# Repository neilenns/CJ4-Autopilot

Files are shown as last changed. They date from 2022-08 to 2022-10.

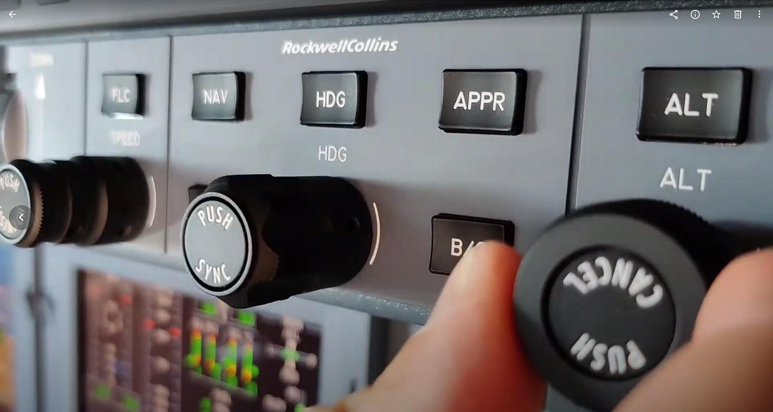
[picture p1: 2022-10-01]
Real world knobs.png

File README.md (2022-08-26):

# KiBot CI/CD template repository for KiCad 6

This repository provides a ready-to-go CI/CD workflow for KiCad 6 with GitHub actions. Using KiCad5? [See my other repo](https://github.com/neilenns/KiBot-CICD-Template).

## Features of this repository template

1. Integration with GitHub releases to automatically produce documentation and
   fabrication files on every GitHub release, including automatic date and version
   stamping of schematics and PCBs.
2. KiBot preflighting on every pull request (ERC/DRC checks disabled by default).
3. VSCode dev container and default build task for easy local testing of KiBot scripts.

## Creating your GitHub repo and KiCad project

To create a KiCad project using this GitHub template:

1. Hit the _Use this template_ button then follow the steps from GitHub to create a copy of the repo. **The repository name must exactly match the name of the KiCad project.
   Do not use spaces in either the repository or the project name.**
2. Clone the new repo locally.
3. Go to _File_ > _New_ > _Project..._ in KiCad.
4. Name the project the exact same name as the GitHub repository name.
5. Uncheck the _Create a new directory for this project_ option. **This is very important!**
6. Save the project into the top level of the folder for the GitHub repository.

Do not use spaces in the GitHub repository or KiCad project name. Use underscores or hyphens instead, for example `TBM930_De-Ice_-_Panel` or `Collins-FMS-3000`.

If you've done all the steps correctly the folder structure will look similar like this:



Notice that the folder name (which is also the GitHub repo name) and project name are exactly the same and there are no spaces.

## Setting up date and version number replacement

The GitHub automation can automatically set the date and version number in the generated schematic and PCBs. Before using this make sure
to set the timezone to your local timezone in the `.github\workflows\documentation-only.yml` and `.github\workflows\release.yml` files.

Version number and date replacement is done on the `%%version%%` and `%%date%%` string wherever they appear in your `.sch` and `.kicad_pcb` files.
Typically you will use them in the _Page settings_ dialog for the schematic and as text in silkscreen and/or copper layers on your board:





## Documentation generated

The following documents are generated on every release build:

- Interactive BOM - HTML
- Schematic - PDF
- PCB front copper and explanatory drawings layers - PDF
- PCB back copper and explanatory drawings layers - PDF
- 3D render - STEP
- PCB front - JPEG
- PCB back - JPEG

These documents can also be generated by manually running the `KiBot - Generate documentation` action on GitHub.

## Fabrication files generated

The following fabrication files are generated on every release build:

- JLCPCB gerbers and drill files, with BOM and placement files for SMT service
- PCBWay gerbers and drill files

The fabrication files can also be generated by manually running the `KiBot - Release` action on GitHub.

## How this works

A complete CodeTour is included in this repository that walks through all the components
of how KiBot scripts and GitHub actions work. [Use github.dev to view the CodeTour](https://github.dev/neilenns/KiBot-CICD-Template)!

## Running builds locally

This repository template includes the files necessary to run in a VSCode dev container,
which dramatically reduces the effort required to use KiBot on Windows machines.

Never used VSCode remote containers before on Windows? Here's how to get set up:

1. From a PowerShell install WSL2 with this command: `wsl --install`
2. Install [Visual Studio Code](https://code.visualstudio.com/Download) and Docker Desktop(https://www.docker.com/products/docker-desktop)
3. Install the [Remote Containers](https://marketplace.visualstudio.com/items?itemName=ms-vscode-remote.remote-containers) extension for VSCode

When installing Docker Desktop you may be told you have to enable virtualization in your computer's BIOS. Setting that up
is outside the scope of this readme but isn't hard. Just do a web search for your motherboard for how to enter the BIOS
and what the exact name of the setting is, then turn it on.

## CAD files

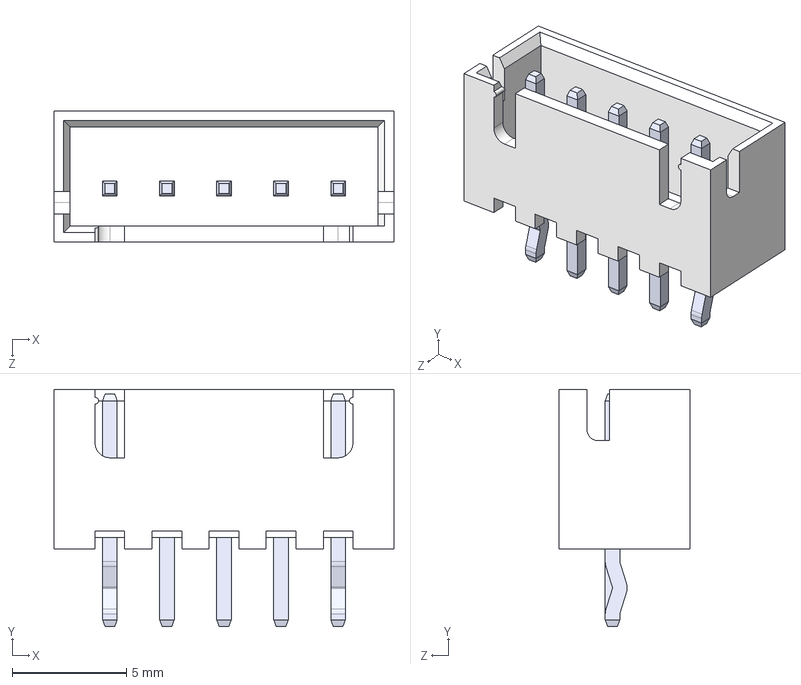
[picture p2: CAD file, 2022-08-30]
3D Models/B5B-XH-A-LF--SN---3DModel-STEP-418109.STEP
14.9 x 10.4 x 5.75 mm

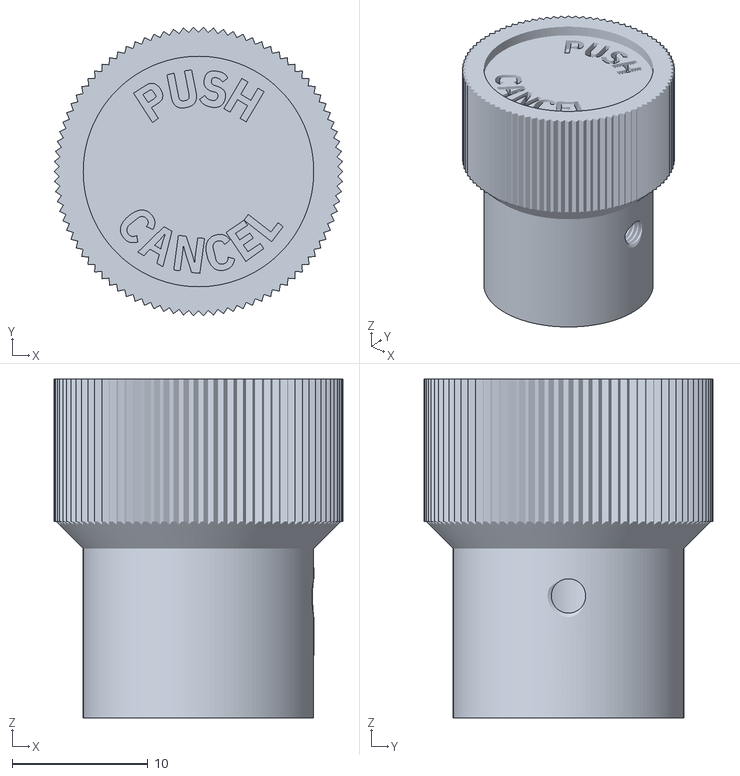
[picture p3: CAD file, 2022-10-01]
3D prints/ALT knob.stl
21.3 x 21.3 x 25.0

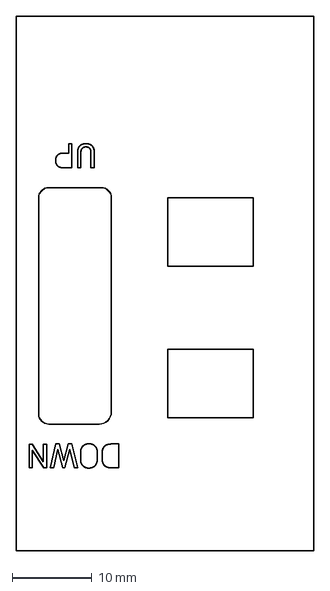
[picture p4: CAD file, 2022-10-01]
down up.dxf
37.3 x 67.2 mm

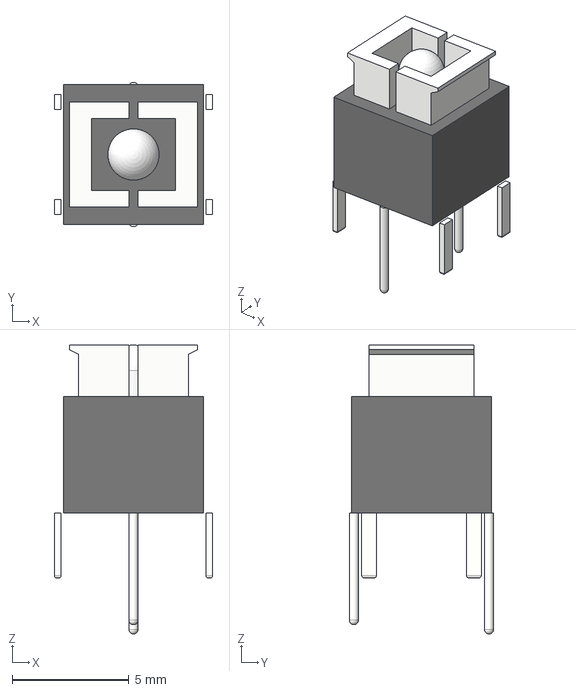
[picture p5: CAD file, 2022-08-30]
3D Models/6x6 LED button.step
6.78 x 6.20 x 12.4 mm

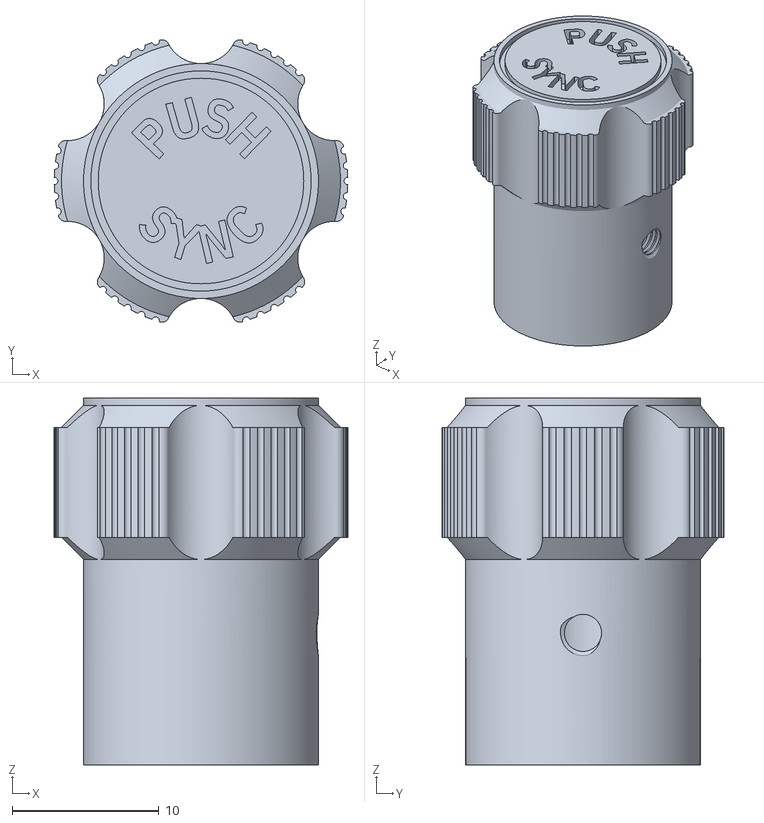
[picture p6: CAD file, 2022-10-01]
3D prints/HDG knob.stl
20.0 x 19.2 x 25.0

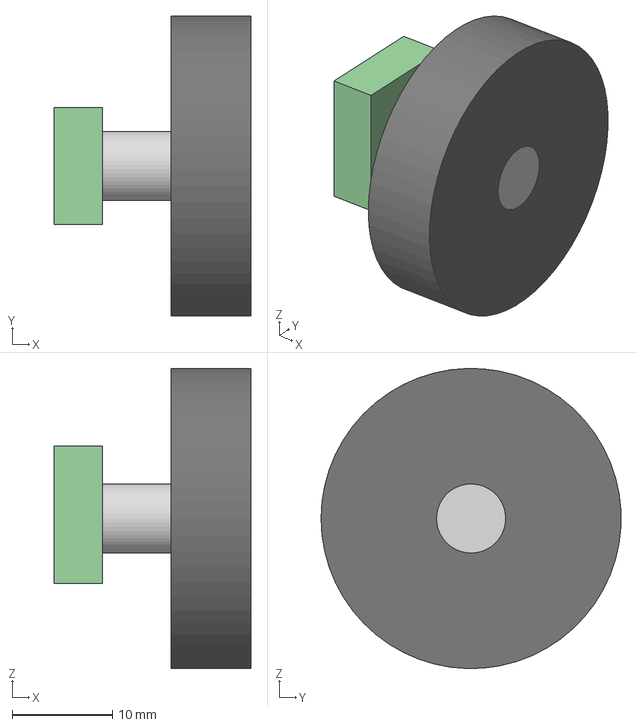
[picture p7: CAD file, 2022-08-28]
3D Models/Right angle encoder.step
19.6 x 30.0 x 30.0 mm

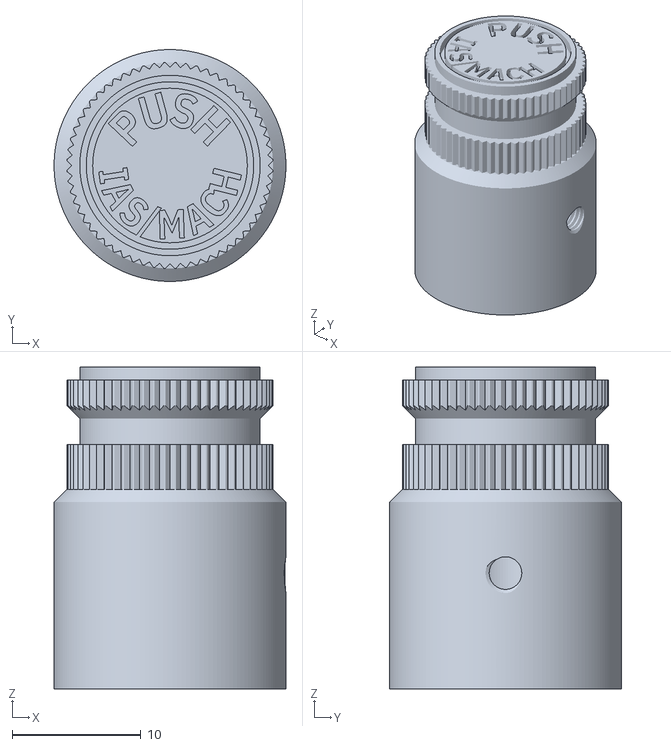
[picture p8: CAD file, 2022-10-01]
3D prints/SPEED knob.stl
18.0 x 18.0 x 25.0

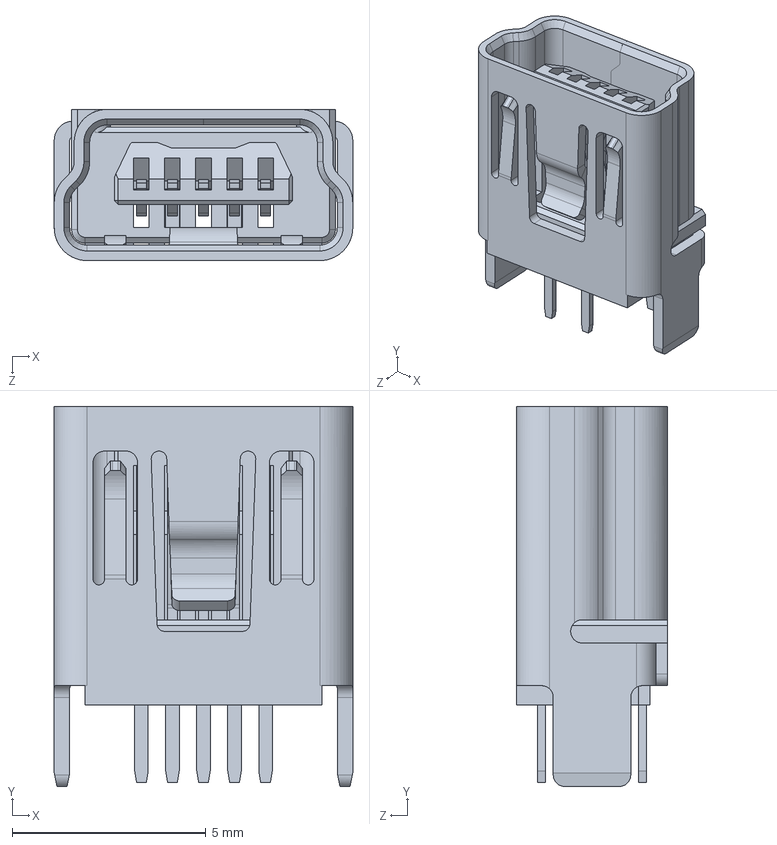
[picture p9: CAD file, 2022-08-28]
3D Models/UE25BE5510H--3DModel-STEP-533217.STEP
7.70 x 9.80 x 3.90 mm

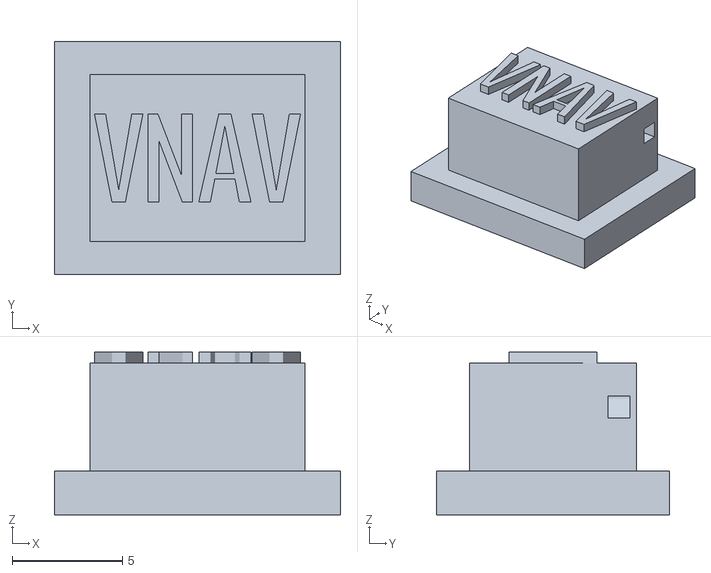
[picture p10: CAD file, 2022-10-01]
3D prints/VNAV cap.stl
13.0 x 10.6 x 7.40

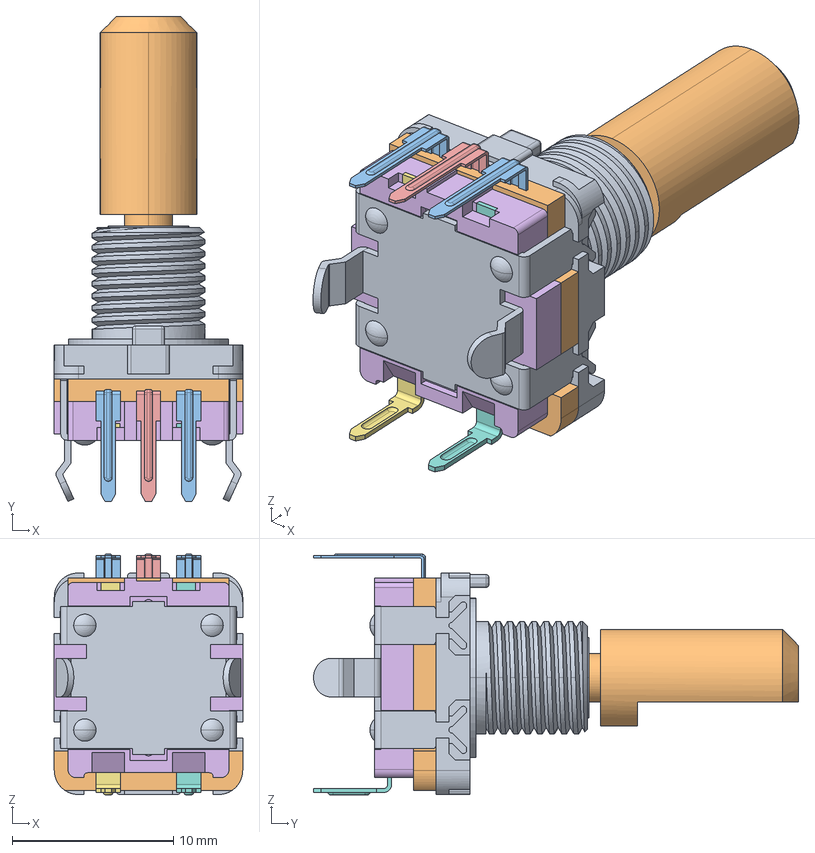
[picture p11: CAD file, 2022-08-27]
3D Models/EN11-HSM1BF20--3DModel-STEP-412949.STEP
11.7 x 30.1 x 14.9 mm

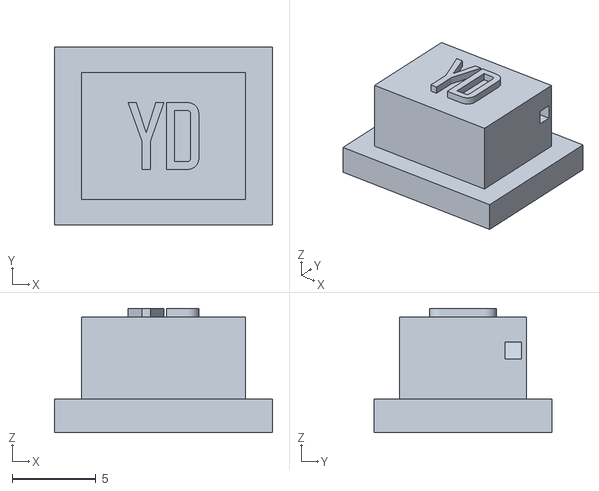
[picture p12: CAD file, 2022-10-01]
3D prints/YD cap.stl
13.0 x 10.6 x 7.40

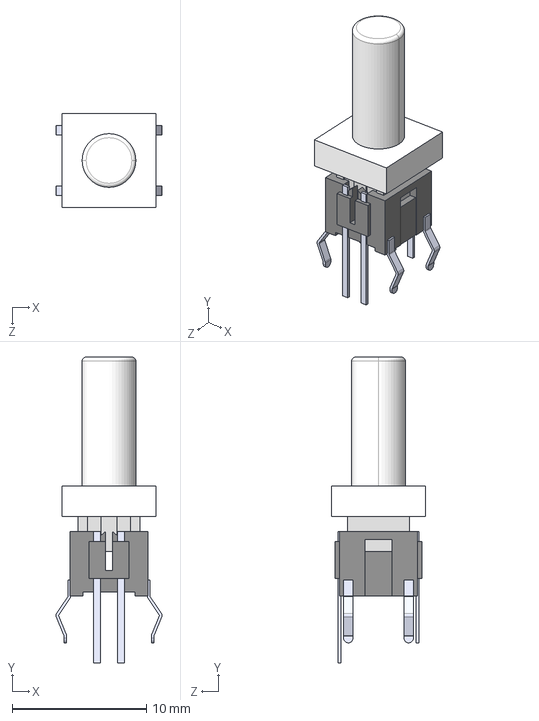
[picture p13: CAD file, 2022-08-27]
3D Models/TC002-N11AS1XT-RGB--3DModel-STEP-418109.STEP
7.90 x 22.8 x 7.00 mm

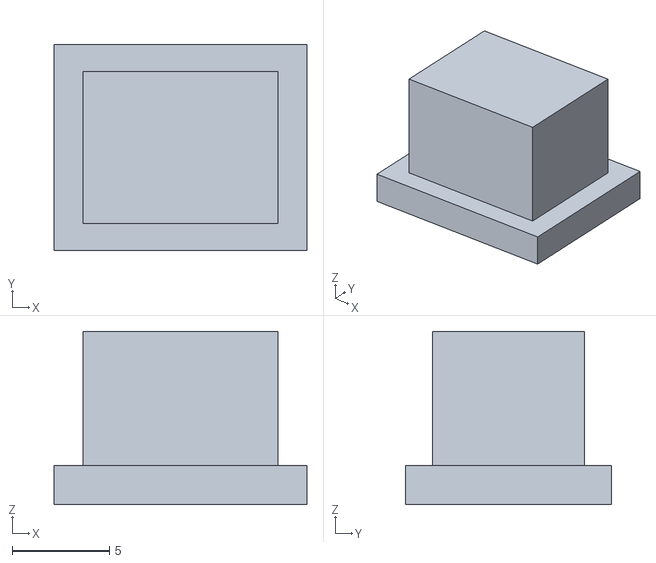
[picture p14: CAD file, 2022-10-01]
3D prints/Blank cap.stl
13.0 x 10.6 x 8.90

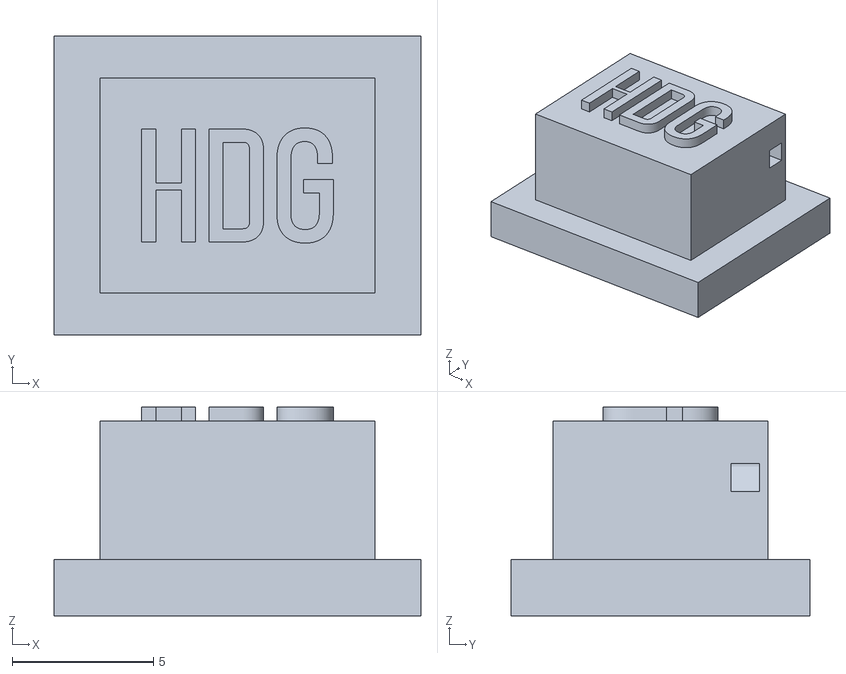
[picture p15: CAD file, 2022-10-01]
3D prints/HDG cap.stl
13.0 x 10.6 x 7.40

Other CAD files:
3D prints/VS cap.stl
3D prints/CRS knob.stl
3D prints/HALF BANK cap.stl
3D prints/AP XFR cap.stl
3D prints/ALT cap.stl
3D prints/APPR cap.stl
3D prints/BC cap.stl
3D prints/Cap.stl
3D prints/FD cap.stl
3D prints/FLC cap.stl
3D prints/Mounting bracket - left.stl
3D prints/Mounting bracket - right.stl
3D prints/NAV cap.stl

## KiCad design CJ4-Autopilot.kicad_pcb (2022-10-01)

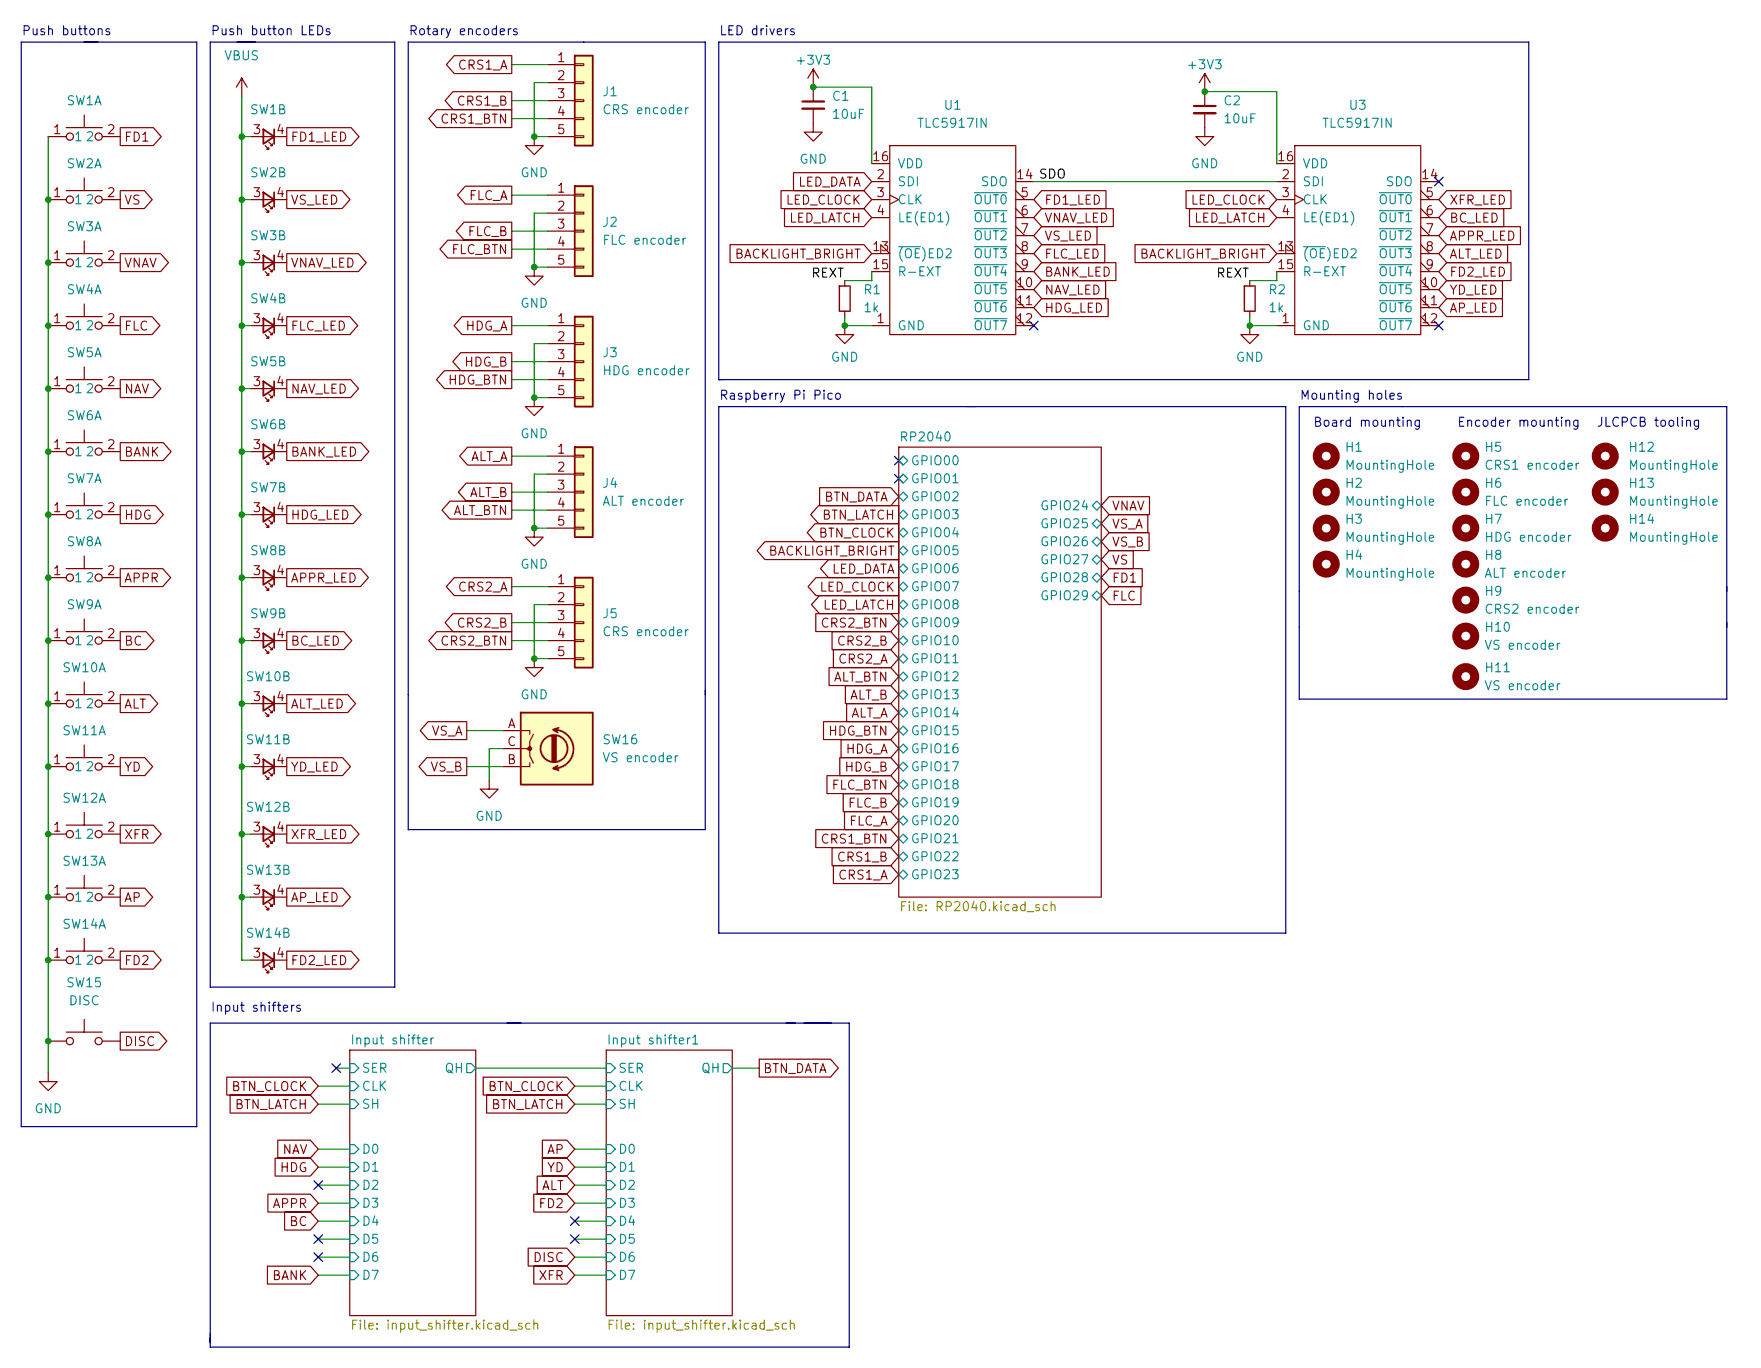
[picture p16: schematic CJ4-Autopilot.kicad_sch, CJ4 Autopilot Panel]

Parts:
C1, C2: 10uF; C_0603_1608Metric; JLC 0603
H1, H2, H3, H4: MountingHole; MountingHole_3.2mm_M3
H5: CRS1 encoder; EN11-HSM1BF20 panel mount
H6: FLC encoder; EN11-HSM1BF20 panel mount
H7: HDG encoder; EN11-HSM1BF20 panel mount
H8: ALT encoder; EN11-HSM1BF20 panel mount
H9: CRS2 encoder; EN11-HSM1BF20 panel mount
H10, H11: VS encoder; MountingHole_3.2mm_M3
H12, H13, H14: MountingHole; JLCPCB_Tooling_Hole
J1, J5: CRS encoder; JST_XH_B5B-XH-A_1x05_P2.50mm_Vertical
J2: FLC encoder; JST_XH_B5B-XH-A_1x05_P2.50mm_Vertical
J3: HDG encoder; JST_XH_B5B-XH-A_1x05_P2.50mm_Vertical
J4: ALT encoder; JST_XH_B5B-XH-A_1x05_P2.50mm_Vertical
R1, R2: 1k; Perfect_0402; JLC 0402
SW1: FD1; SW_PUSH_6mm
SW2: VS; SW_PUSH_6mm
SW3: VNAV; SW_PUSH_6mm
SW4: FLC; SW_PUSH_6mm
SW5: NAV; SW_PUSH_6mm
SW6: BANK; SW_PUSH_6mm
SW7: HDG; SW_PUSH_6mm
SW8: APPR; SW_PUSH_6mm
SW9: BC; SW_PUSH_6mm
SW10: ALT; SW_PUSH_6mm
SW11: YD; SW_PUSH_6mm
SW12: XFR; SW_PUSH_6mm
SW13: AP; SW_PUSH_6mm
SW14: FD2; SW_PUSH_6mm
SW15: DISC; SW_PUSH_6mm
SW16: VS encoder; EN11-VNB1BQ15
U1, U3: TLC5917IN; SOIC-16_3.9x9.9mm_P1.27mm

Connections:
+3V3: C1.1, C2.1, U1.16 (VDD), U3.16 (VDD); also elsewhere on the board
/REXT: R1.1, R2.1, U1.15 (R-EXT), U3.15 (R-EXT)
/SDO: U1.14 (SDO), U3.2 (SDI)
ALT: SW10.2; also elsewhere on the board
ALT_A: J4.1; also elsewhere on the board
ALT_B: J4.3; also elsewhere on the board
ALT_BTN: J4.4; also elsewhere on the board
ALT_LED: SW10.4, U3.8 (~OUT3)
AP: SW13.2; also elsewhere on the board
APPR: SW8.2; also elsewhere on the board
APPR_LED: SW8.4, U3.7 (~OUT2)
AP_LED: SW13.4, U3.11 (~OUT6)
BACKLIGHT_BRIGHT: U1.13 (~(OE)ED2), U3.13 (~(OE)ED2); also elsewhere on the board
BANK: SW6.2; also elsewhere on the board
BANK_LED: SW6.4, U1.9 (~OUT4)
BC: SW9.2; also elsewhere on the board
BC_LED: SW9.4, U3.6 (~OUT1)
CRS1_A: J1.1; also elsewhere on the board
CRS1_B: J1.3; also elsewhere on the board
CRS1_BTN: J1.4; also elsewhere on the board
CRS2_A: J5.1; also elsewhere on the board
CRS2_B: J5.3; also elsewhere on the board
CRS2_BTN: J5.4; also elsewhere on the board
DISC: SW15.2; also elsewhere on the board
FD1: SW1.2; also elsewhere on the board
FD1_LED: SW1.4, U1.5 (~OUT0)
FD2: SW14.2; also elsewhere on the board
FD2_LED: SW14.4, U3.9 (~OUT4)
FLC: SW4.2; also elsewhere on the board
FLC_A: J2.1; also elsewhere on the board
FLC_B: J2.3; also elsewhere on the board
FLC_BTN: J2.4; also elsewhere on the board
FLC_LED: SW4.4, U1.8 (~OUT3)
GND: C1.2, C2.2, J1.2, J1.5, J2.2, J2.5, J3.2, J3.5, J4.2, J4.5, J5.2, J5.5, R1.2, R2.2, SW1.1, SW2.1, SW3.1, SW4.1, SW5.1, SW6.1, SW7.1, SW8.1, SW9.1, SW10.1, SW11.1, SW12.1, SW13.1, SW14.1, SW15.1, SW16.C, U1.1 (GND), U3.1 (GND); also elsewhere on the board
HDG: SW7.2; also elsewhere on the board
HDG_A: J3.1; also elsewhere on the board
HDG_B: J3.3; also elsewhere on the board
HDG_BTN: J3.4; also elsewhere on the board
HDG_LED: SW7.4, U1.11 (~OUT6)
LED_CLOCK: U1.3 (CLK), U3.3 (CLK); also elsewhere on the board
LED_DATA: U1.2 (SDI); also elsewhere on the board
LED_LATCH: U1.4 (LE(ED1)), U3.4 (LE(ED1)); also elsewhere on the board
NAV: SW5.2; also elsewhere on the board
NAV_LED: SW5.4, U1.10 (~OUT5)
VBUS: SW1.3, SW2.3, SW3.3, SW4.3, SW5.3, SW6.3, SW7.3, SW8.3, SW9.3, SW10.3, SW11.3, SW12.3, SW13.3, SW14.3; also elsewhere on the board
VNAV: SW3.2; also elsewhere on the board
VNAV_LED: SW3.4, U1.6 (~OUT1)
VS: SW2.2; also elsewhere on the board
VS_A: SW16.A; also elsewhere on the board
VS_B: SW16.B; also elsewhere on the board
VS_LED: SW2.4, U1.7 (~OUT2)
XFR: SW12.2; also elsewhere on the board
XFR_LED: SW12.4, U3.5 (~OUT0)
YD: SW11.2; also elsewhere on the board
YD_LED: SW11.4, U3.10 (~OUT5)

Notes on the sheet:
JLCPCB tooling
Mounting holes
Input shifters
LED drivers
Board mounting
Rotary encoders
Encoder mounting
Raspberry Pi Pico
Push button LEDs
Push buttons

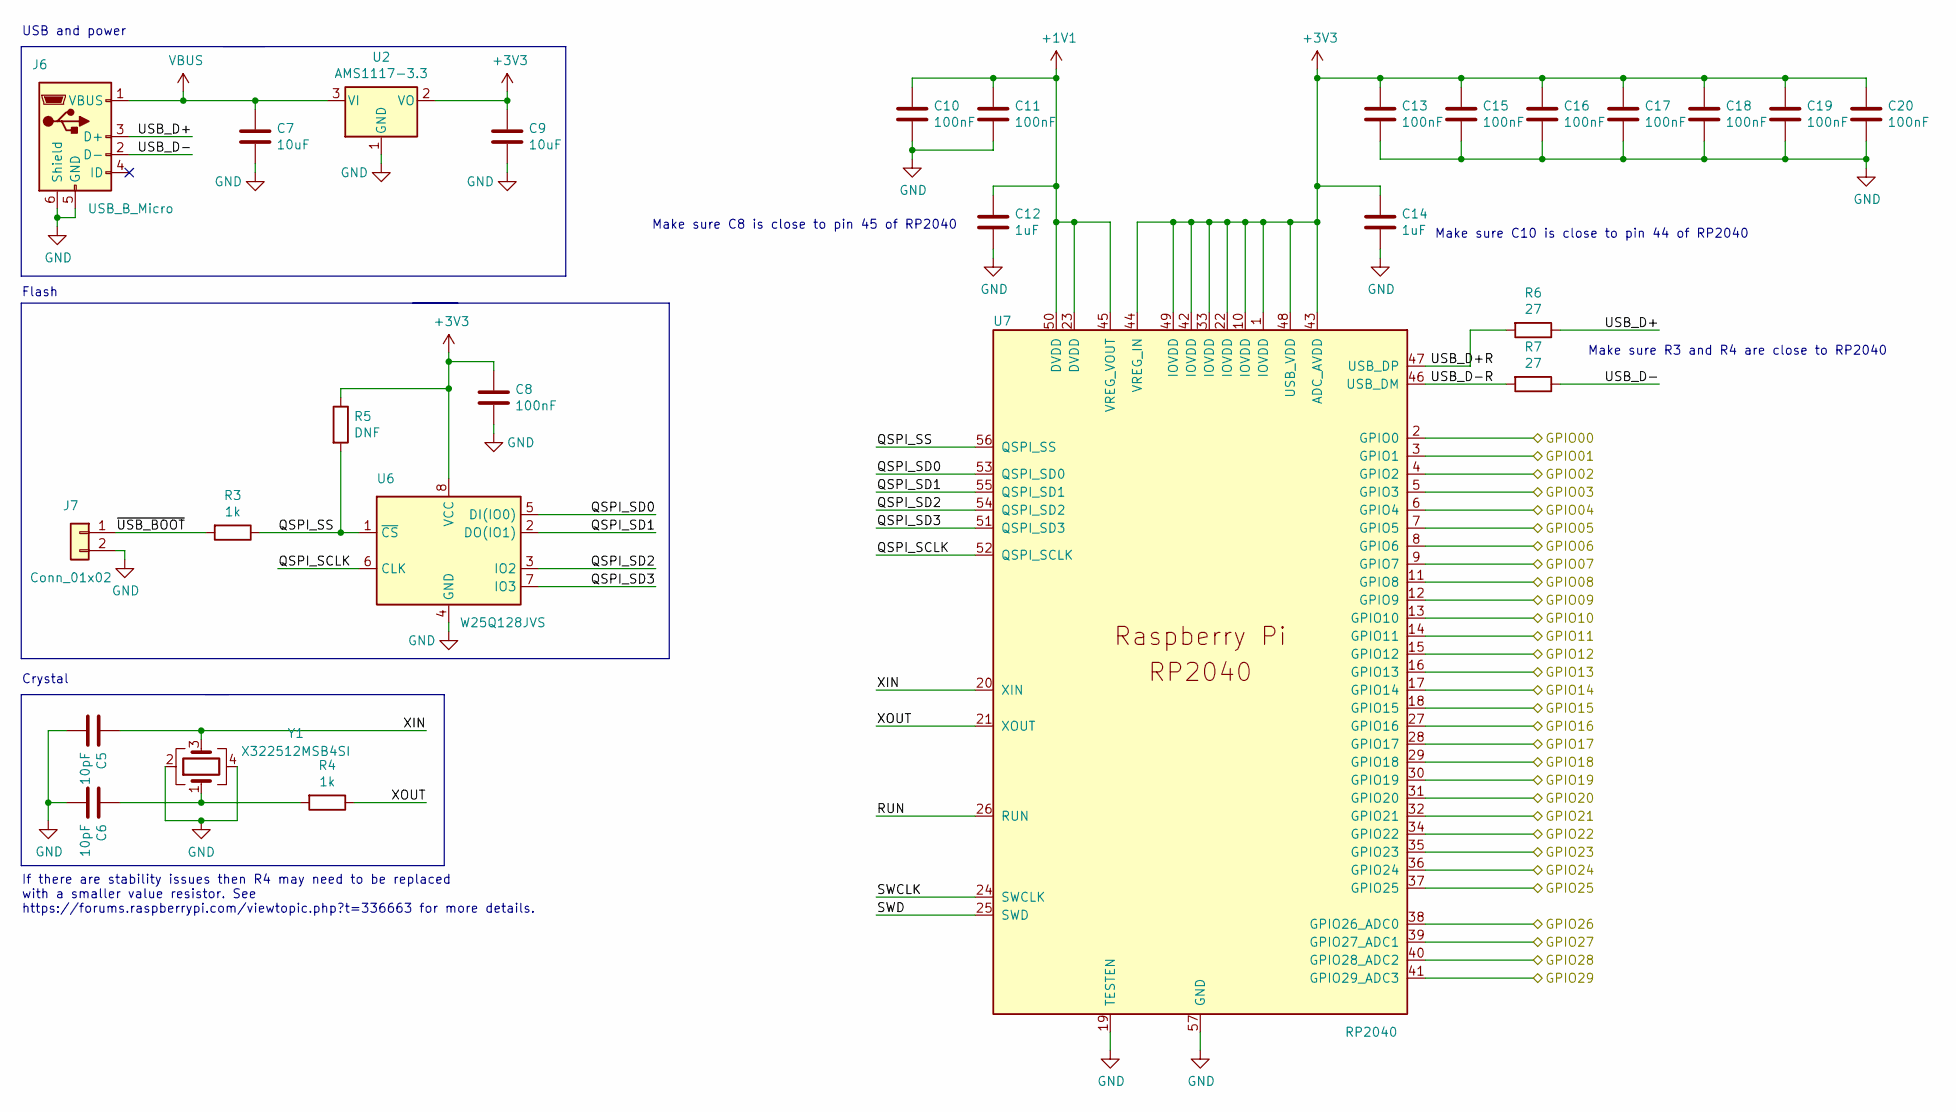
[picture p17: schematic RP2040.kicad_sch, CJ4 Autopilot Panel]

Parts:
C5, C6: 10pF; Perfect_0402; JLC 0402
C7, C9: 10uF; C_0603_1608Metric; JLC 0603
C8, C10, C11, C13, C15, C16, C17, C18, C19, C20: 100nF; Perfect_0402; JLC 0402
C12, C14: 1uF; Perfect_0402; JLC 0402
J6: USB_B_Micro; USB_B_Mini_Amphenol_UE25BE5510H
J7: Conn_01x02; PinHeader_1x02_P2.54mm_Vertical
R3, R4: 1k; Perfect_0402; JLC 0402
R5: DNF; R_1206_3216Metric_Pad1.30x1.75mm_HandSolder
R6, R7: 27; R_0603_1608Metric; JLC 0603
U2: AMS1117-3.3; SOT-223-3_TabPin2; JLC SOT-223
U6: W25Q128JVS; SOIC-8_5.23x5.23mm_P1.27mm; JLC SOIC-8_5.3x5.3x1.27P
U7: RP2040; RP2040-QFN-56; JLC LQFN-56_EP_7.0x7.0x0.4P
Y1: X322512MSB4SI; Crystal_SMD_3225-4Pin_3.2x2.5mm; JLC SMD-3225_4P

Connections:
+1V1: C10.1, C11.1, C12.1, U7.23 (DVDD), U7.45 (VREG_VOUT), U7.50 (DVDD)
+3V3: C8.1, C9.1, C13.1, C14.1, C15.1, C16.1, C17.1, C18.1, C19.1, C20.1, R5.1, U2.2 (VO), U6.8 (VCC), U7.1 (IOVDD), U7.10 (IOVDD), U7.22 (IOVDD), U7.33 (IOVDD), U7.42 (IOVDD), U7.43 (ADC_AVDD), U7.44 (VREG_IN), U7.48 (USB_VDD), U7.49 (IOVDD); also elsewhere on the board
/RP2040/GPIO00: U7.2 (GPIO0)
/RP2040/GPIO01: U7.3 (GPIO1)
/RP2040/QSPI_SCLK: U6.6 (CLK), U7.52 (QSPI_SCLK)
/RP2040/QSPI_SD0: U6.5 (DI(IO0)), U7.53 (QSPI_SD0)
/RP2040/QSPI_SD1: U6.2 (DO(IO1)), U7.55 (QSPI_SD1)
/RP2040/QSPI_SD2: U6.3 (IO2), U7.54 (QSPI_SD2)
/RP2040/QSPI_SD3: U6.7 (IO3), U7.51 (QSPI_SD3)
/RP2040/QSPI_SS: R3.1, R5.2, U6.1 (~CS), U7.56 (QSPI_SS)
/RP2040/RUN: U7.26 (RUN)
/RP2040/SWCLK: U7.24 (SWCLK)
/RP2040/SWD: U7.25 (SWD)
/RP2040/USB_D+: J6.3 (D+), R6.1
/RP2040/USB_D+R: R6.2, U7.47 (USB_DP)
/RP2040/USB_D-: J6.2 (D-), R7.1
/RP2040/USB_D-R: R7.2, U7.46 (USB_DM)
/RP2040/XIN: C5.1, U7.20 (XIN), Y1.3
/RP2040/XOUT: R4.1, U7.21 (XOUT)
/RP2040/~USB_BOOT: J7.1, R3.2
ALT_A: U7.17 (GPIO14); also elsewhere on the board
ALT_B: U7.16 (GPIO13); also elsewhere on the board
ALT_BTN: U7.15 (GPIO12); also elsewhere on the board
BACKLIGHT_BRIGHT: U7.7 (GPIO5); also elsewhere on the board
BTN_CLOCK: U7.6 (GPIO4); also elsewhere on the board
BTN_DATA: U7.4 (GPIO2); also elsewhere on the board
BTN_LATCH: U7.5 (GPIO3); also elsewhere on the board
CRS1_A: U7.35 (GPIO23); also elsewhere on the board
CRS1_B: U7.34 (GPIO22); also elsewhere on the board
CRS1_BTN: U7.32 (GPIO21); also elsewhere on the board
CRS2_A: U7.14 (GPIO11); also elsewhere on the board
CRS2_B: U7.13 (GPIO10); also elsewhere on the board
CRS2_BTN: U7.12 (GPIO9); also elsewhere on the board
FD1: U7.40 (GPIO28_ADC2); also elsewhere on the board
FLC: U7.41 (GPIO29_ADC3); also elsewhere on the board
FLC_A: U7.31 (GPIO20); also elsewhere on the board
FLC_B: U7.30 (GPIO19); also elsewhere on the board
FLC_BTN: U7.29 (GPIO18); also elsewhere on the board
GND: C5.2, C6.2, C7.2, C8.2, C9.2, C10.2, C11.2, C12.2, C13.2, C14.2, C15.2, C16.2, C17.2, C18.2, C19.2, C20.2, J6.5 (GND), J6.6 (Shield), J7.2, U2.1 (GND), U6.4 (GND), U7.19 (TESTEN), U7.57 (GND), Y1.2, Y1.4; also elsewhere on the board
HDG_A: U7.27 (GPIO16); also elsewhere on the board
HDG_B: U7.28 (GPIO17); also elsewhere on the board
HDG_BTN: U7.18 (GPIO15); also elsewhere on the board
LED_CLOCK: U7.9 (GPIO7); also elsewhere on the board
LED_DATA: U7.8 (GPIO6); also elsewhere on the board
LED_LATCH: U7.11 (GPIO8); also elsewhere on the board
unnamed: C6.1, R4.2, Y1.1
VBUS: C7.1, J6.1 (VBUS), U2.3 (VI); also elsewhere on the board
VNAV: U7.36 (GPIO24); also elsewhere on the board
VS: U7.39 (GPIO27_ADC1); also elsewhere on the board
VS_A: U7.37 (GPIO25); also elsewhere on the board
VS_B: U7.38 (GPIO26_ADC0); also elsewhere on the board

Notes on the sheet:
USB and power
Crystal
Flash
If there are stability issues then R4 may need to be replaced with a smaller value resistor. See https://forums.raspberrypi.com/viewtopic.php?t=336663 for more details.
Make sure C8 is close to pin 45 of RP2040
Make sure R3 and R4 are close to RP2040
Make sure C10 is close to pin 44 of RP2040

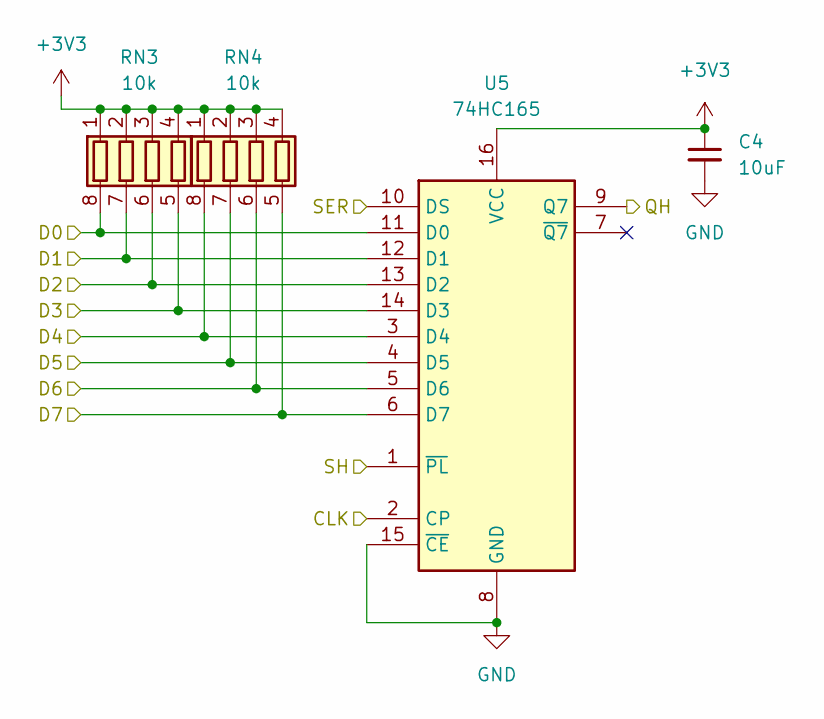
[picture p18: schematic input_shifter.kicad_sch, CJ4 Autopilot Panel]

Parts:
C4: 10uF; C_0603_1608Metric; JLC 0603
RN3, RN4: 10k; R_Array_Convex_4x0603; JLC 0603_x4
U5: 74HC165; SOIC-16_3.9x9.9mm_P1.27mm; JLC SOIC-16_3.9x9.9x1.27P

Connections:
+3V3: C4.1, RN3.1 (R1.1), RN3.2 (R2.1), RN3.3 (R3.1), RN3.4 (R4.1), RN4.1 (R1.1), RN4.2 (R2.1), RN4.3 (R3.1), RN4.4 (R4.1), U5.16 (VCC); also elsewhere on the board
/Input shifter1/D4: RN4.8 (R1.2), U5.3 (D4)
/Input shifter1/D5: RN4.7 (R2.2), U5.4 (D5)
/Input shifter/QH: U5.10 (DS); also elsewhere on the board
ALT: RN3.6 (R3.2), U5.13 (D2); also elsewhere on the board
AP: RN3.8 (R1.2), U5.11 (D0); also elsewhere on the board
BTN_CLOCK: U5.2 (CP); also elsewhere on the board
BTN_DATA: U5.9 (Q7); also elsewhere on the board
BTN_LATCH: U5.1 (~PL); also elsewhere on the board
DISC: RN4.6 (R3.2), U5.5 (D6); also elsewhere on the board
FD2: RN3.5 (R4.2), U5.14 (D3); also elsewhere on the board
GND: C4.2, U5.8 (GND), U5.15 (~CE); also elsewhere on the board
XFR: RN4.5 (R4.2), U5.6 (D7); also elsewhere on the board
YD: RN3.7 (R2.2), U5.12 (D1); also elsewhere on the board

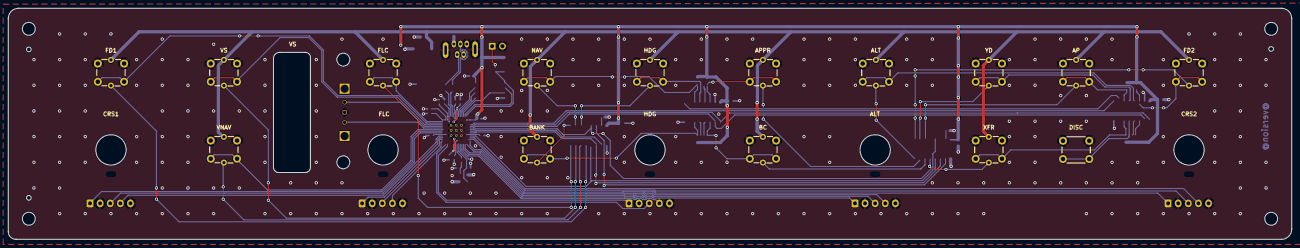
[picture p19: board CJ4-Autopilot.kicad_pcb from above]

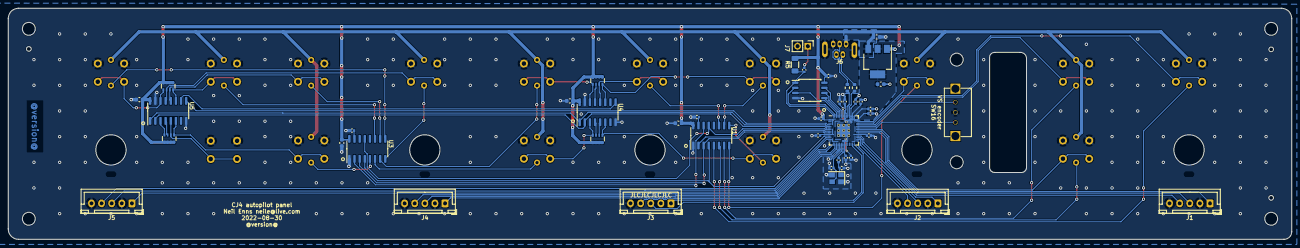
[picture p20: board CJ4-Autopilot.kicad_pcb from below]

Board: 2 copper layers, 317.5 x 57.1 mm, 76 parts (47 on the bottom side), 79 nets.

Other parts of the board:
C3: 10uF; C_0603_1608Metric
RN1, RN2: 10k; R_Array_Convex_4x0603
U4: 74HC165; SOIC-16_3.9x9.9mm_P1.27mm

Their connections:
+3V3: C3.1, RN1.1 (R1.1), RN1.2 (R2.1), RN1.3 (R3.1), RN1.4 (R4.1), RN2.1 (R1.1), RN2.2 (R2.1), RN2.3 (R3.1), RN2.4 (R4.1), U4.16 (VCC); also elsewhere on the board
/Input shifter/D2: RN1.6 (R3.2), U4.13 (D2)
/Input shifter/D5: RN2.7 (R2.2), U4.4 (D5)
/Input shifter/D6: RN2.6 (R3.2), U4.5 (D6)
/Input shifter/QH: U4.9 (Q7); also elsewhere on the board
APPR: RN1.5 (R4.2), U4.14 (D3); also elsewhere on the board
BANK: RN2.5 (R4.2), U4.6 (D7); also elsewhere on the board
BC: RN2.8 (R1.2), U4.3 (D4); also elsewhere on the board
BTN_CLOCK: U4.2 (CP); also elsewhere on the board
BTN_LATCH: U4.1 (~PL); also elsewhere on the board
GND: C3.2, U4.8 (GND), U4.15 (~CE); also elsewhere on the board
HDG: RN1.7 (R2.2), U4.12 (D1); also elsewhere on the board
NAV: RN1.8 (R1.2), U4.11 (D0); also elsewhere on the board

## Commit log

2022-08-25 Initial work, lost interest. Bah.
    [CJ4-Autopilot.kicad_pcb, CJ4-Autopilot.kicad_sch, input_shifter.kicad_sch]
2022-08-25 Added pico
    [CJ4-Autopilot.kicad_sch, input_shifter.kicad_sch]
2022-08-26 Full schematic done
    [CJ4-Autopilot.kicad_pcb, CJ4-Autopilot.kicad_sch, input_shifter.kicad_sch]
2022-08-26 Update version tag
    [CJ4-Autopilot.kicad_pcb, CJ4-Autopilot.kicad_sch, input_shifter.kicad_sch]
2022-08-26 Initial board layout, still a lot of work to do
    [CJ4-Autopilot.kicad_pcb, CJ4-Autopilot.kicad_sch, input_shifter.kicad_sch]
2022-08-27 Add RP2040 directly to the board
    [CJ4-Autopilot.kicad_pcb, CJ4-Autopilot.kicad_sch, EN11-HSM1BF20--3DModel-STEP-412949.STEP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]
2022-08-28 RP2040 wired up, warning cleanup
    [CJ4-Autopilot.kicad_pcb, CJ4-Autopilot.kicad_sch, RP2040.kicad_sch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]
2022-08-28 Update encoder footprint, USB trace width
    [CJ4-Autopilot.kicad_pcb, CJ4-Autopilot.kicad_sch, RP2040.kicad_sch]
2022-08-28 Add model for right angle encoder, adjust opening
    [CJ4-Autopilot.kicad_pcb, Right angle encoder.step]
2022-08-28 All power routed???
    [CJ4-Autopilot.kicad_pcb]
2022-08-29 Moved chips, rotated encoder. Lots of traces, it's gonna work!
    [CJ4-Autopilot.kicad_pcb, CJ4-Autopilot.kicad_sch]
2022-08-29 Left side fully connected
    [CJ4-Autopilot.kicad_pcb, CJ4-Autopilot.kicad_sch]
2022-08-30 Tons and tons of traces
    [CJ4-Autopilot.kicad_pcb, CJ4-Autopilot.kicad_sch, input_shifter.kicad_sch]
2022-08-30 Fully routed!
    [CJ4-Autopilot.kicad_pcb, CJ4-Autopilot.kicad_sch, input_shifter.kicad_sch]
2022-08-30 Added 3d models
    [6x6 LED button.step, B5B-XH-A-LF--SN---3DModel-STEP-418109.STEP, CJ4-Autopilot.kicad_pcb]
2022-08-30 Cleanup based on feedback
    [CJ4-Autopilot.kicad_pcb]
2022-08-30 Update silkscreen, fix gerber output
    [CJ4-Autopilot.kicad_pcb, CJ4-Autopilot.kicad_sch, input_shifter.kicad_sch]
2022-08-30 Via stitching, hole cleanup, silkscreen
    [CJ4-Autopilot.kicad_pcb]
2022-08-30 Change drill origin
    [CJ4-Autopilot.kicad_pcb]
2022-08-30 JLCPCB rotation update, add missing pin 1 indicator
    [CJ4-Autopilot.kicad_pcb, CJ4-Autopilot.kicad_sch, input_shifter.kicad_sch]
2022-08-30 Fix broken version text, add more vias
    [CJ4-Autopilot.kicad_pcb]
2022-08-30 More missing versions
    [CJ4-Autopilot.kicad_pcb, CJ4-Autopilot.kicad_sch, RP2040.kicad_sch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]
2022-08-31 Add missing net labels
    [CJ4-Autopilot.kicad_pcb, CJ4-Autopilot.kicad_sch, RP2040.kicad_sch]
2022-08-31 Update crystal capacitors
    [CJ4-Autopilot.kicad_sch, RP2040.kicad_sch]
2022-09-01 Change all 3d models to .step
    [CJ4-Autopilot.kicad_pcb]
2022-10-01 Tons of 3D designs
    [ALT cap.stl, ALT knob.stl, AP XFR cap.stl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]
